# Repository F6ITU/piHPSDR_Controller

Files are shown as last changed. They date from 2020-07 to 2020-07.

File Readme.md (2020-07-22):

'''PiHPSDR, a embedded SDR controler for the OpenHPSDR Software Defined Radio familly'''

This repository is a "pseudo fork" of a Raspberry Pi based SDR controler created by Kjell Karlsen LA2NI and Laurence Baker G8NJJ
for the hardware project, and by John Melton G0ORX for the software part.

The original software repository could be found at https://github.com/g0orx/pihpsdr 

The whole KiCAD design effort has been made by Matthis Schmieder, DB9MAT https://github.com/mathisschmieder. May he be thanked for the quality of his work 
 
His schematic is in fact a simplified version or G0ORX's project (https://github.com/g0orx/pihpsdr/blob/master/controller/PiHPSDR_Controller_MK_II_Rev.2_Schema.zip), 
using single axis encoders instead hard to find dual axis devices. 

Assembly instructions -in French language- could be found on the Electrolab's Wiki https://wiki.electrolab.fr/Projets:Lab:2020:PiHPSDR

This very simple Ham Radio project is perfect for beginners who intend to beginners strengthen their experience in the SMD field.
 
 An interactive BOM could be downloaded from the BOM directory (iBom Pihpsdr controler.html), and a complete Excel spreadsheet 
 gives the references of each component used, using mostly the Mouser catalog

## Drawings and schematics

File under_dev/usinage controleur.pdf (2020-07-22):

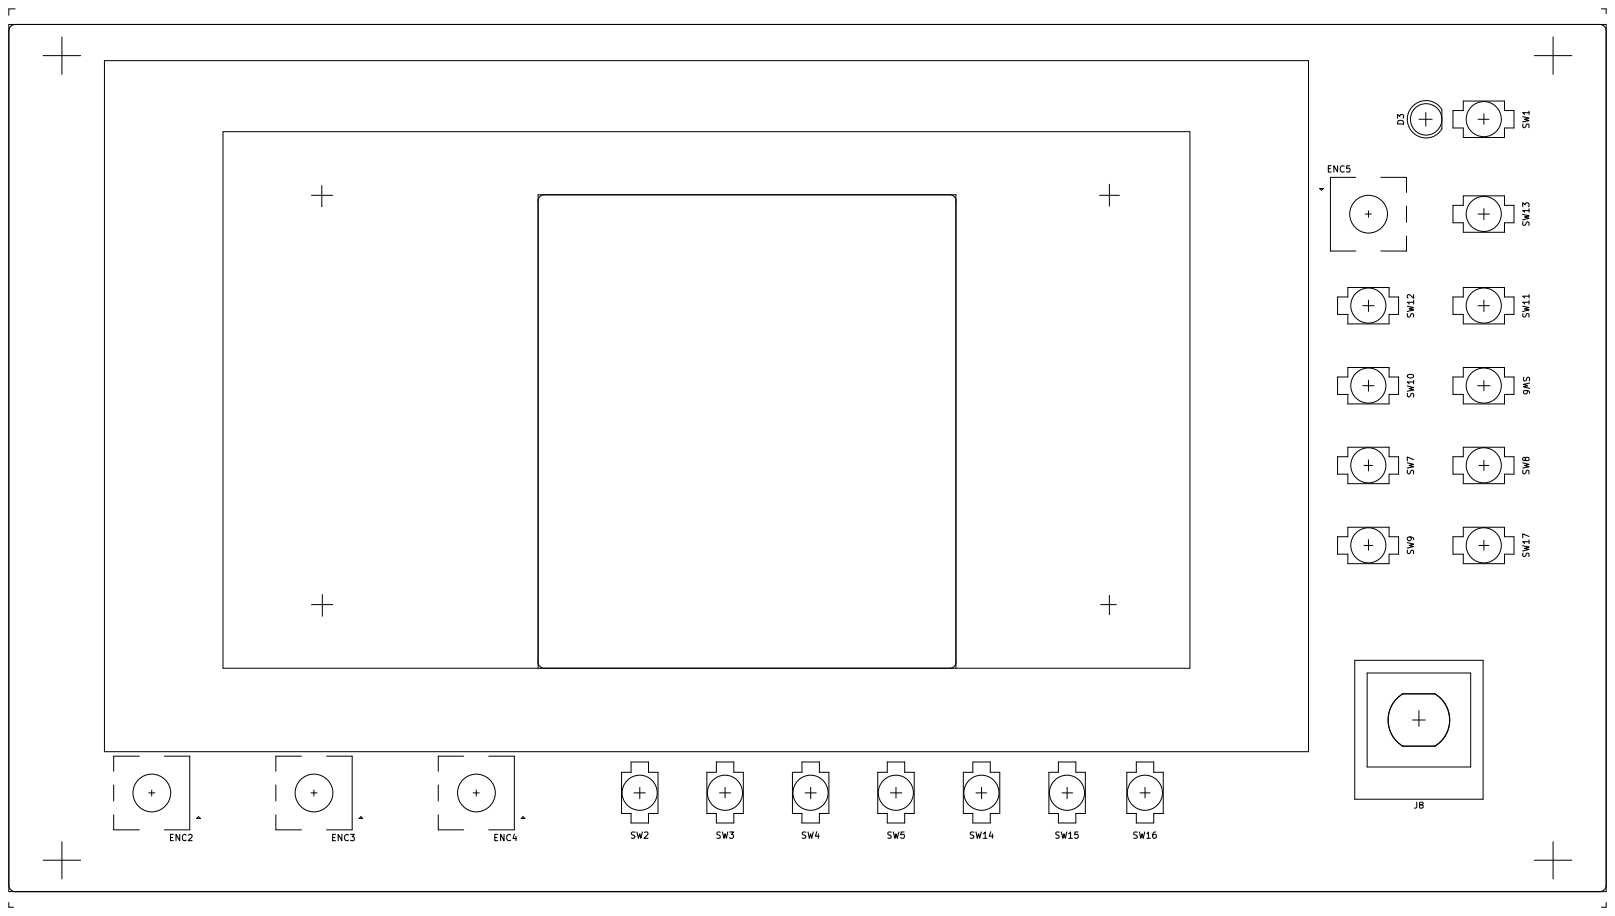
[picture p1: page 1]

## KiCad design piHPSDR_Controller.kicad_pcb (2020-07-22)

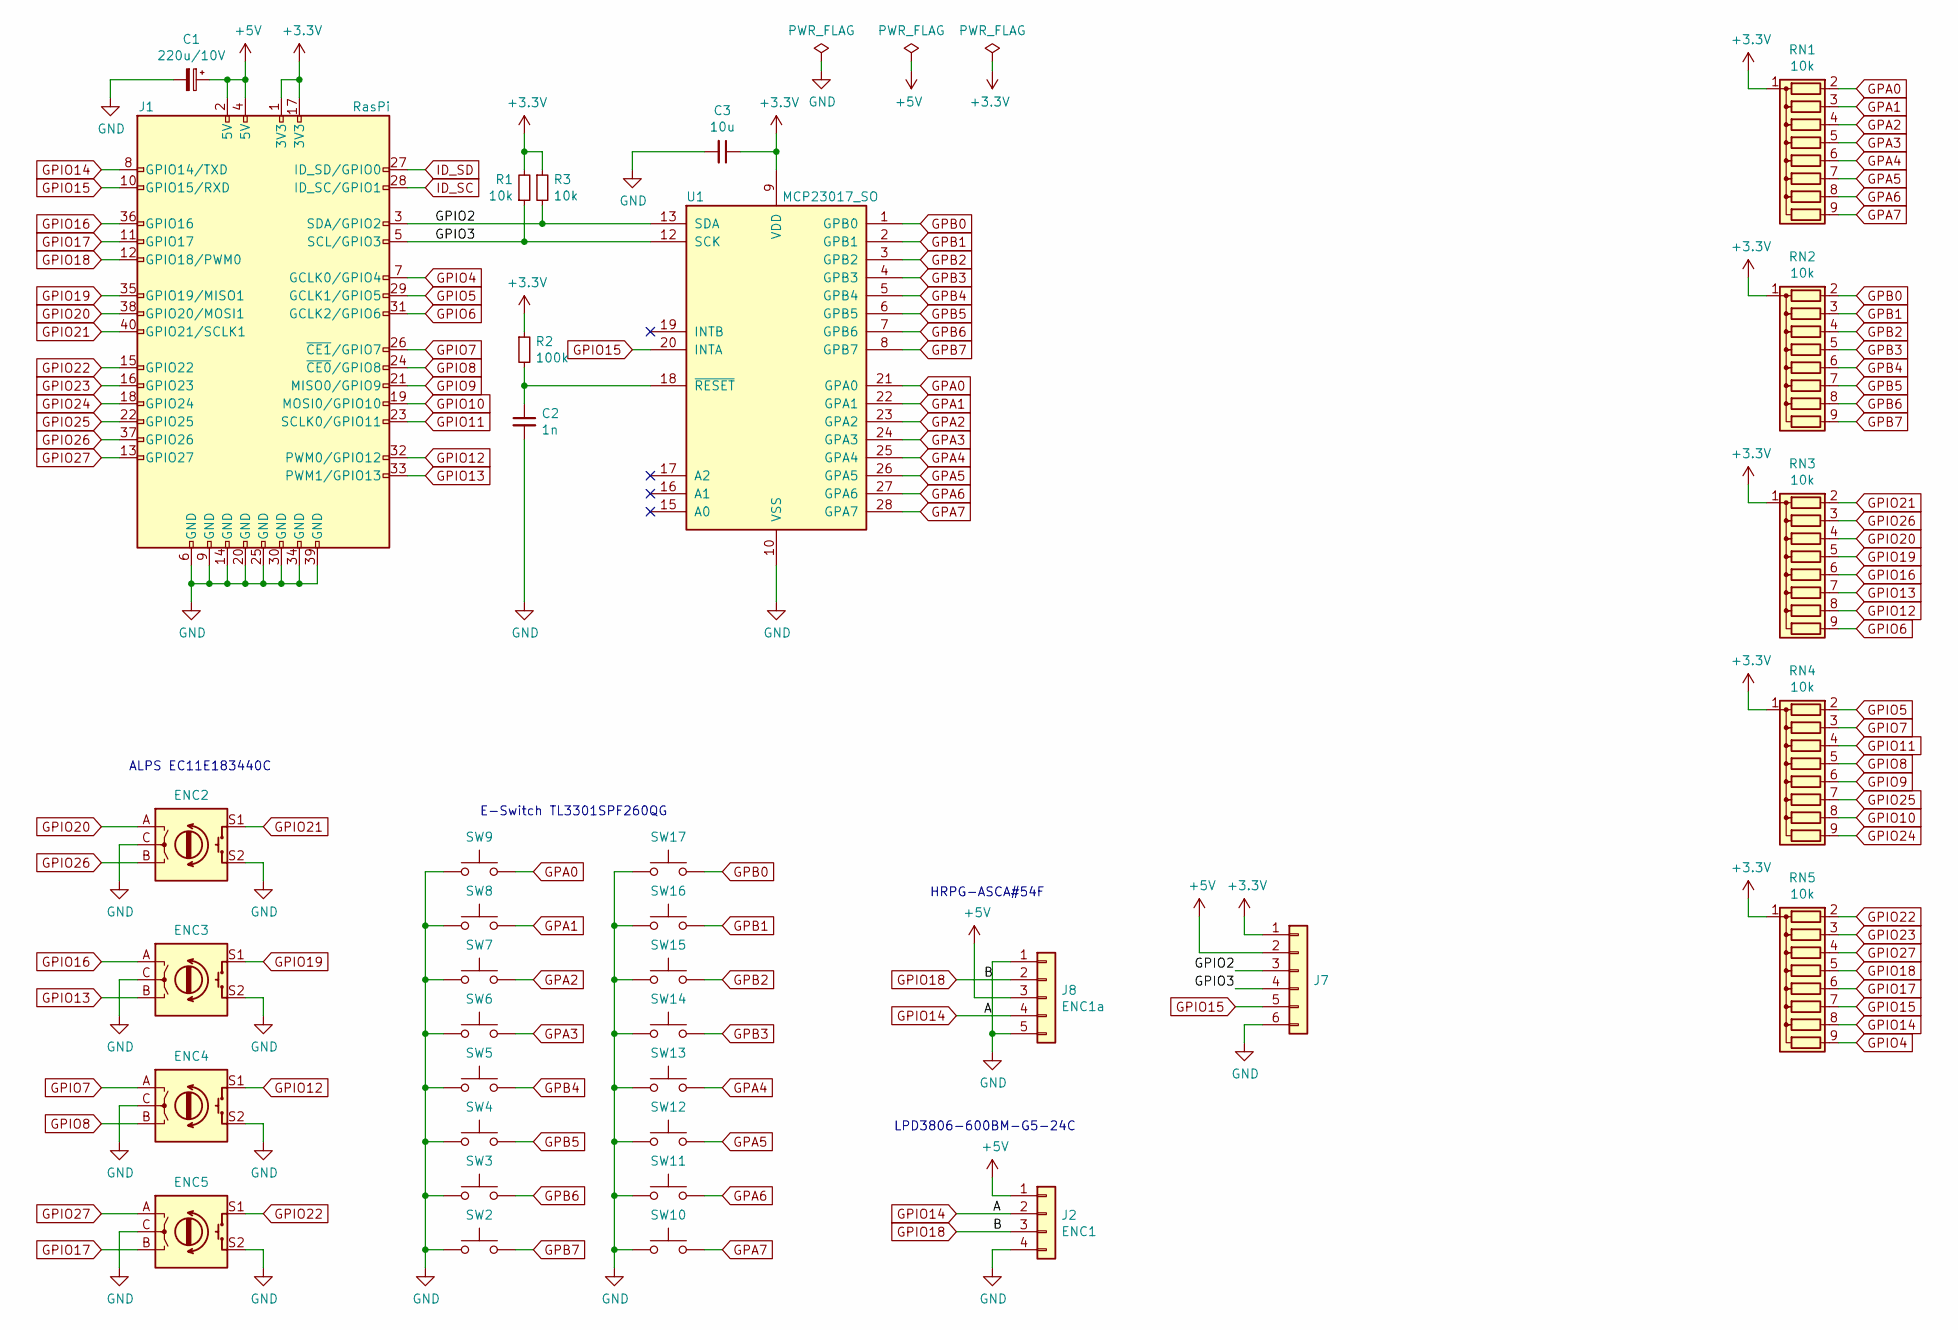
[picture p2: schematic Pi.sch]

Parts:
C1: 220u/10V; CP_EIA-7343-31_Kemet-D
C2: 1n; C_0603_1608Metric
C3: 10u; C_0603_1608Metric
ENC2, ENC3, ENC4, ENC5: Rotary_Encoder_Switch; RotaryEncoder_Alps_EC11E-Switch_Vertical_H20mm
J1: RasPi; raspberrypi_2_3
J2: ENC1; PinHeader_1x04_P2.54mm_Vertical
J7: Conn_01x06; PinHeader_1x06_P2.54mm_Vertical
J8: ENC1a; HRPG-AXXX
R1, R3: 10k; R_0603_1608Metric
R2: 100k; R_0603_1608Metric
RN1: 10k; R_Cat16-8; Partno CAY16-103J8LF
RN2, RN3, RN4, RN5: 10k; R_Cat16-8
SW2, SW3, SW4, SW5, SW6, SW7, SW8, SW9, SW10, SW11, SW12, SW13, SW14, SW15, SW16, SW17: SW_Push; TL3301AF160QG
U1: MCP23017_SO; SOIC-28W_7.5x17.9mm_P1.27mm

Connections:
+3V3: C3.1, J1.1 (3V3), J1.17 (3V3), J7.1, R1.2, R2.1, R3.1, RN1.1 (common), RN2.1 (common), RN3.1 (common), RN4.1 (common), RN5.1 (common), U1.9 (VDD)
+5V: C1.1, J1.2 (5V), J1.4 (5V), J2.1, J7.2, J8.3; also elsewhere on the board
/Raspberry Pi/GPIO2: J1.3 (SDA/GPIO2), J7.3, R3.2, U1.13 (SDA)
/Raspberry Pi/GPIO3: J1.5 (SCL/GPIO3), J7.4, R1.1, U1.12 (SCK)
GND: C1.2, C2.2, C3.2, ENC2.C, ENC2.S2, ENC3.C, ENC3.S2, ENC4.C, ENC4.S2, ENC5.C, ENC5.S2, J1.6 (GND), J1.9 (GND), J1.14 (GND), J1.20 (GND), J1.25 (GND), J1.30 (GND), J1.34 (GND), J1.39 (GND), J2.4, J7.6, J8.1, J8.5, SW2.1, SW3.1, SW4.1, SW5.1, SW6.1, SW7.1, SW8.1, SW9.1, SW10.1, SW11.1, SW12.1, SW13.1, SW14.1, SW15.1, SW16.1, SW17.1, U1.10 (VSS); also elsewhere on the board
GPA0: RN1.2 (R1), SW9.2, U1.21 (GPA0)
GPA1: RN1.3 (R2), SW8.2, U1.22 (GPA1)
GPA2: RN1.4 (R3), SW7.2, U1.23 (GPA2)
GPA3: RN1.5 (R4), SW6.2, U1.24 (GPA3)
GPA4: RN1.6 (R5), SW13.2, U1.25 (GPA4)
GPA5: RN1.7 (R6), SW12.2, U1.26 (GPA5)
GPA6: RN1.8 (R7), SW11.2, U1.27 (GPA6)
GPA7: RN1.9 (R8), SW10.2, U1.28 (GPA7)
GPB0: RN2.2 (R1), SW17.2, U1.1 (GPB0)
GPB1: RN2.3 (R2), SW16.2, U1.2 (GPB1)
GPB2: RN2.4 (R3), SW15.2, U1.3 (GPB2)
GPB3: RN2.5 (R4), SW14.2, U1.4 (GPB3)
GPB4: RN2.6 (R5), SW5.2, U1.5 (GPB4)
GPB5: RN2.7 (R6), SW4.2, U1.6 (GPB5)
GPB6: RN2.8 (R7), SW3.2, U1.7 (GPB6)
GPB7: RN2.9 (R8), SW2.2, U1.8 (GPB7)
GPIO4: J1.7 (GCLK0/GPIO4), RN5.9 (R8)
GPIO5: J1.29 (GCLK1/GPIO5), RN4.2 (R1)
GPIO6: J1.31 (GCLK2/GPIO6), RN3.9 (R8)
GPIO7: ENC4.A, J1.26 (~CE1~/GPIO7), RN4.3 (R2)
GPIO8: ENC4.B, J1.24 (~CE0~/GPIO8), RN4.5 (R4)
GPIO9: J1.21 (MISO0/GPIO9), RN4.6 (R5)
GPIO10: J1.19 (MOSI0/GPIO10), RN4.8 (R7)
GPIO11: J1.23 (SCLK0/GPIO11), RN4.4 (R3)
GPIO12: ENC4.S1, J1.32 (PWM0/GPIO12), RN3.8 (R7)
GPIO13: ENC3.B, J1.33 (PWM1/GPIO13), RN3.7 (R6)
GPIO14: J1.8 (GPIO14/TXD), J2.2, J8.4, RN5.8 (R7)
GPIO15: J1.10 (GPIO15/RXD), J7.5, RN5.7 (R6), U1.20 (INTA)
GPIO16: ENC3.A, J1.36 (GPIO16), RN3.6 (R5)
GPIO17: ENC5.B, J1.11 (GPIO17), RN5.6 (R5)
GPIO18: J1.12 (GPIO18/PWM0), J2.3, J8.2, RN5.5 (R4)
GPIO19: ENC3.S1, J1.35 (GPIO19/MISO1), RN3.5 (R4)
GPIO20: ENC2.A, J1.38 (GPIO20/MOSI1), RN3.4 (R3)
GPIO21: ENC2.S1, J1.40 (GPIO21/SCLK1), RN3.2 (R1)
GPIO22: ENC5.S1, J1.15 (GPIO22), RN5.2 (R1)
GPIO23: J1.16 (GPIO23), RN5.3 (R2)
GPIO24: J1.18 (GPIO24), RN4.9 (R8)
GPIO25: J1.22 (GPIO25), RN4.7 (R6)
GPIO26: ENC2.B, J1.37 (GPIO26), RN3.3 (R2)
GPIO27: ENC5.A, J1.13 (GPIO27), RN5.4 (R3)
unnamed: C2.1, R2.2, U1.18 (~RESET~)

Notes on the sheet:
E-Switch TL3301SPF260QG
LPD3806-600BM-G5-24C
ALPS EC11E183440C
HRPG-ASCA#54F

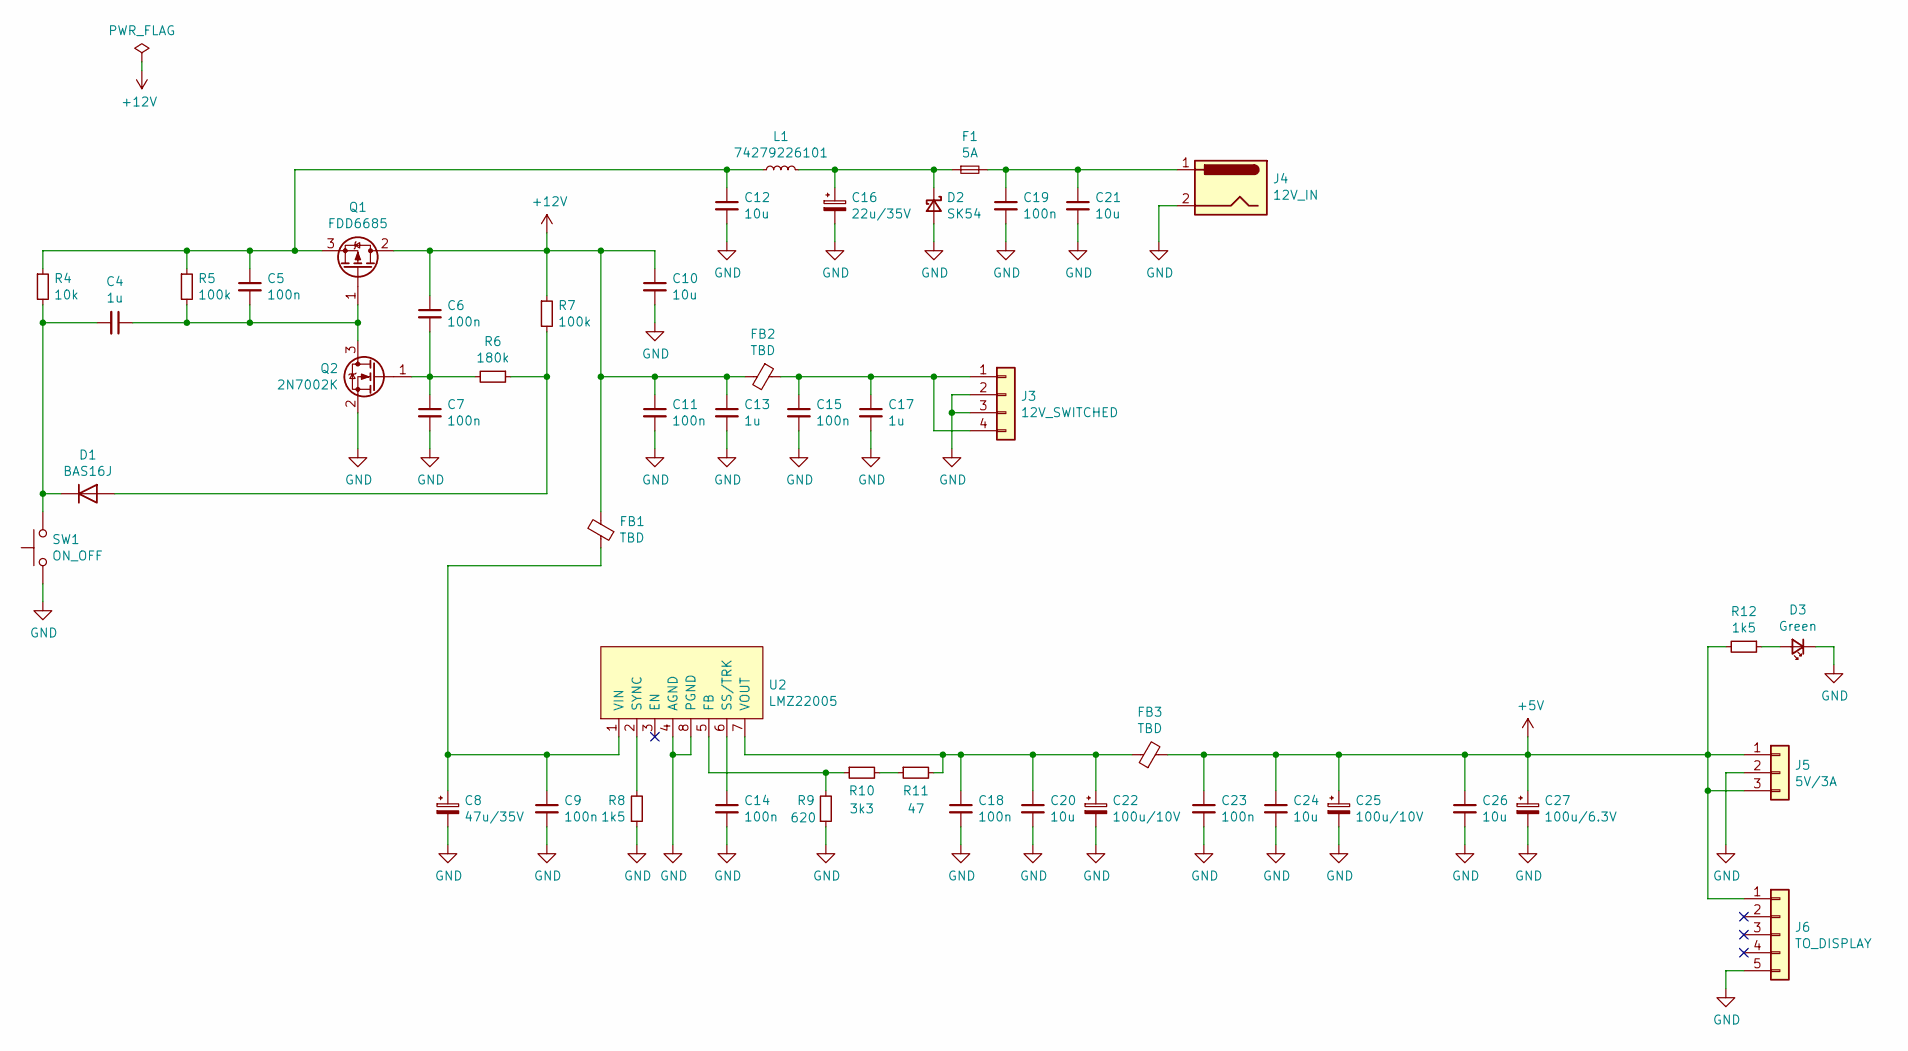
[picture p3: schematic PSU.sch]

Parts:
C4, C13, C17: 1u; C_0603_1608Metric
C5, C6, C7, C9, C11, C14, C15, C18, C19, C23: 100n; C_0603_1608Metric
C8: 47u/35V; CP_EIA-7343-43_Kemet-X
C10, C12, C20, C21, C24, C26: 10u; C_0603_1608Metric
C16: 22u/35V; CP_EIA-7343-31_Kemet-D
C22, C25: 100u/10V; CP_EIA-7132-28_AVX-C
C27: 100u/6.3V; CP_EIA-3216-18_Kemet-A
D1: BAS16J; SOT-323_SC-70
D2: SK54; D_SMC
D3: Green; LED_D5.0mm
F1: 5A; Fuse_1206_3216Metric
FB1, FB2, FB3: TBD; L_0603_1608Metric
J3: 12V_SWITCHED; PinHeader_1x04_P2.54mm_Vertical
J4: 12V_IN; BarrelJack_CUI_PJ-063AH_Horizontal
J5: 5V/3A; PinHeader_1x03_P2.54mm_Vertical
J6: TO_DISPLAY; PinHeader_1x05_P2.54mm_Vertical
L1: 74279226101; L_1812_4532Metric
Q1: FDD6685; TO-252-3_TabPin2
Q2: 2N7002K; SOT-23
R4: 10k; R_0603_1608Metric
R5, R7: 100k; R_0603_1608Metric
R6: 180k; R_0603_1608Metric
R8, R12: 1k5; R_0603_1608Metric
R9: 620; R_0603_1608Metric
R10: 3k3; R_0603_1608Metric
R11: 47; R_0603_1608Metric
SW1: ON_OFF; TL3301AF160QG
U2: LMZ22005; TO-PMOD-7

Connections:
+5V: C23.1, C24.1, C25.1, C26.1, C27.1, FB3.2, J5.1, J5.3, J6.1, R12.2; also elsewhere on the board
+12V: C6.1, C10.1, C11.1, C13.1, FB1.2, FB2.2, Q1.2 (D), R7.1
GND: C7.2, C8.2, C9.2, C10.2, C11.2, C12.2, C13.2, C14.2, C15.2, C16.2, C17.2, C18.2, C19.2, C20.2, C21.2, C22.2, C23.2, C24.2, C25.2, C26.2, C27.2, D2.2 (A), D3.1 (K), J3.2, J3.3, J4.2, J5.2, J6.5, Q2.2 (S), R8.1, R9.1, SW1.1, U2.4 (AGND), U2.8 (PGND); also elsewhere on the board
unnamed: C4.1, C5.2, Q1.1 (G), Q2.3 (D), R5.2
unnamed: C4.2, D1.3 (K), R4.2, SW1.2
unnamed: C6.2, C7.1, Q2.1 (G), R6.2
unnamed: C8.1, C9.1, FB1.1, U2.1 (VIN)
unnamed: C5.1, C12.1, L1.1, Q1.3 (S), R4.1, R5.1
unnamed: C14.1, U2.6 (SS/TRK)
unnamed: C15.1, C17.1, FB2.1, J3.1, J3.4
unnamed: C16.1, D2.1 (K), F1.1, L1.2
unnamed: C18.1, C20.1, C22.1, FB3.1, R11.2, U2.7 (VOUT)
unnamed: C19.1, C21.1, F1.2, J4.1
unnamed: D1.1 (A), R6.1, R7.2
unnamed: D3.2 (A), R12.1
unnamed: R8.2, U2.2 (SYNC)
unnamed: R9.2, R10.1, U2.5 (FB)
unnamed: R10.2, R11.1

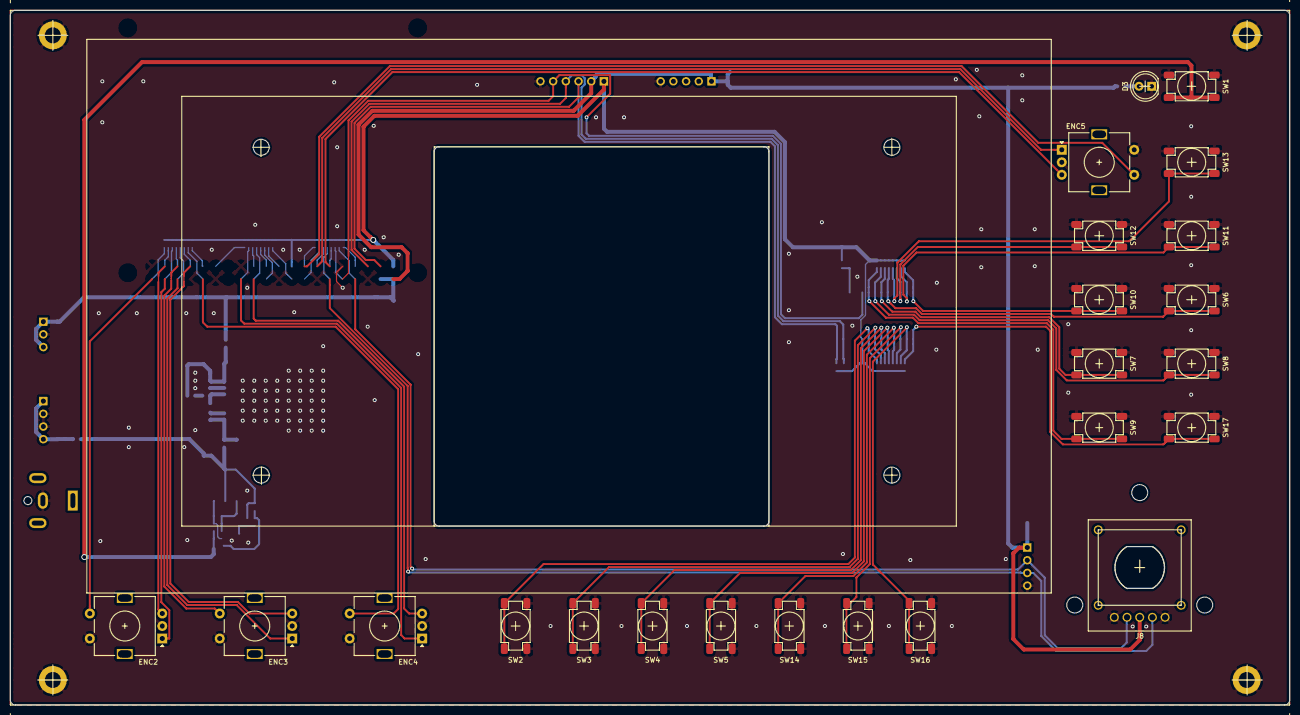
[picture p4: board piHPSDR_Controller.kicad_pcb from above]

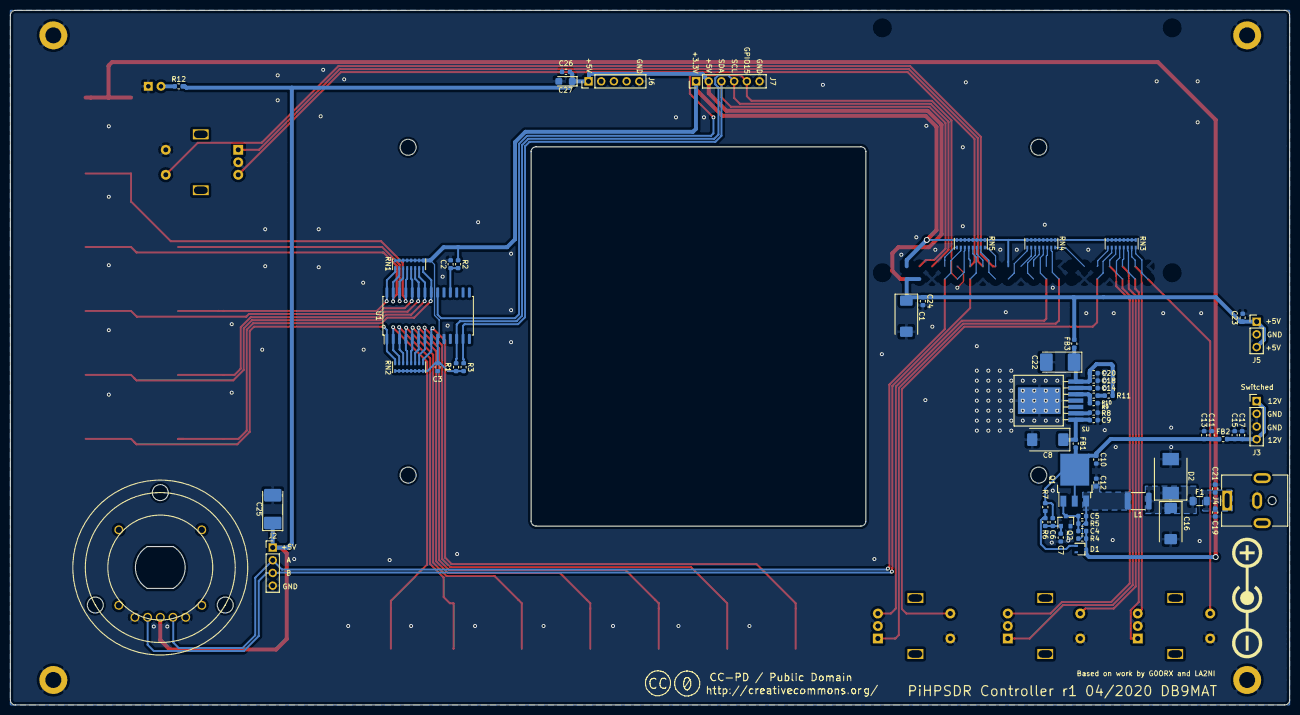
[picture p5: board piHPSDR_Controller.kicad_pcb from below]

Board: 2 copper layers, 256.0 x 139.0 mm, 88 parts (61 on the bottom side), 53 nets.

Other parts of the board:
 : MountingHole_3.2mm_M3_DIN965_Pad
 #2,  #3,  #4: MountingHole_3.2mm_M3_DIN965_Pad

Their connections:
GND: .1, #2.1, #3.1, #4.1; also elsewhere on the board
